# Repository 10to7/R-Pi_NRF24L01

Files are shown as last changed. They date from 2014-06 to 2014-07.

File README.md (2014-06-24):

Raspberry Pi NRF24L01
==================

A breakout board for one of the cheap NRF24L01 modules for Raspbery Pi.

##Module pin outs
Top view of the NRF24L01 modules pins are assumed to be:

8 Pin
```no-highlight
|GND  |3v3  |
|CE   |CSN  |
|SCK  |MOSI |
|MISO |IRQ (not connected)|
```

10 Pin
```no-highlight
|3v3  |3v3  |
|CE   |CSN  |
|SCK  |MOSI |
|MISO |IRQ (not connected)|
|GND  |GND  |
```

Please check that your modules match one of these pin layouts otherwise you risk damaging your raspberry pi or the NRF24L01 module.

| Top | Bottom |
|---|---|
|PCBfront|PCBback|

##Schematic
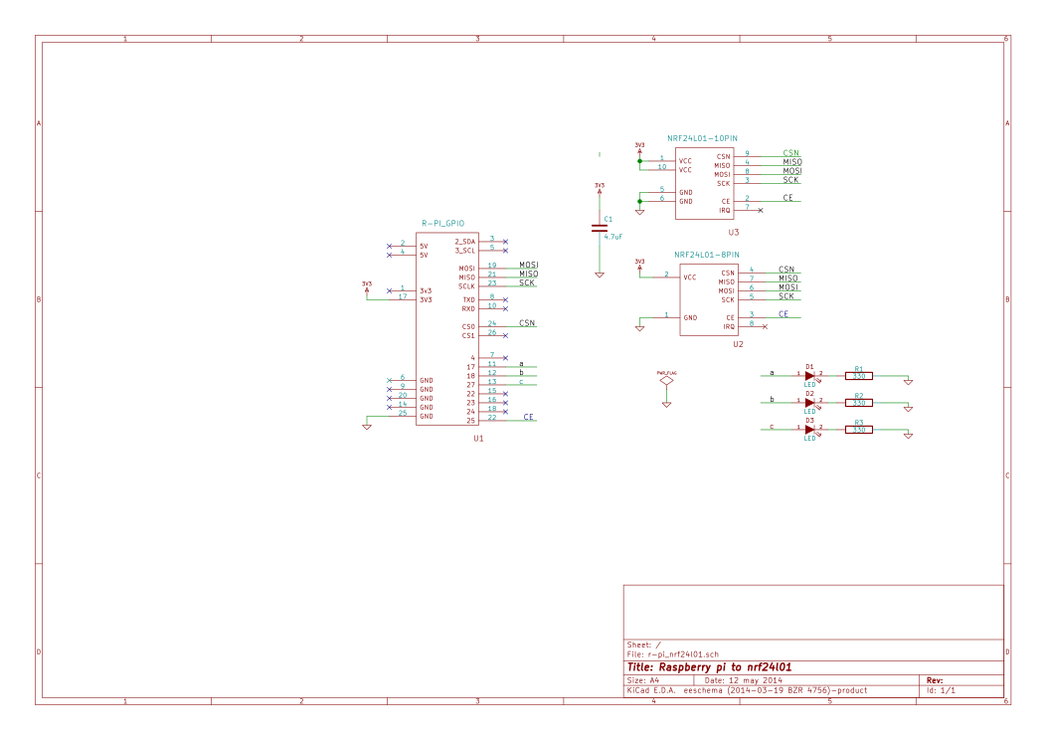
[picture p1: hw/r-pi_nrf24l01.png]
Schematic


[PCBfront]: front.png "PCB front"
[PCBback]: back.png "PCB Back"
[Schematic]: hw/r-pi_nrf24l01.png "Schematic"

Select the resistor values for the LED's. The raspberry pi can only source up to 16mA through the GPIO pins.
Suggested bill of matterials includes:

http://uk.farnell.com/ part numbers:

|Part | Description | Qty |Cost (GBP)|
|---|---|---|---|
|209-9221 | 0603 Red LED | 1 |0.054 |
|122-6372 | 0603 Green LED | 1 |0.052 |
|209-9222 | 0603 Orange LED | 1 | 0.056 |
|207-3958 | 0402 100 Ohm | 3 | 0.021 |
|175-9414 | 0805 4.7uF | 1 | 0.041 |

2.54mm female headers are also required for the board. A single 2x13 16 position header for the raspberry pi and a 2x4 8 position or 2x5 10 position female header for the NRF24L01 module.

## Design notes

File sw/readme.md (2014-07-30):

Example of running the NRF24L01 on the R-Pi
=====

Using Occidentals:
https://learn.adafruit.com/adafruit-raspberry-pi-educational-linux-distro/occidentalis-v0-dot-2

Ensure you enable SPI.

$ git clone https://github.com/10to7/RF24.git <br/>
$ cd RF24 <br />
$ cd librf24-rpi/librf24

Compile the library <br />
$ make                                
$ sudo make install              
$ sudo ldconfig -v | grep librf
     librf24.so.1 -> librf24.so.1.0

$ cd ../examples/ <br />
You should now be in RF24/librf24-rpi/librf24/examples

$ make

To run the programs, type 

$ sudo ./rpi-hub

To send data to the hub on a second raspberry pi run <br />
$ sudo ./sendto_hub

Alternatively use the nRF24_sendto_hub arduino script. You will need to add the nRF24 library to your arduino ide to get the NRF24.h

Wire up your module to the arduino as follows:

|NRF24L01 	| Arduino Nano	|
|---		|---		|
|CE		| D9		|
|SS		| D10		|
|MOSI		| D11		|
|MISO		| D12		|
|SCK		| D13		|
|3v3		| 3v3		|
|GND		| GND		|

Add an additional 100uF capacitor between 3v3 and GND. The arduino nano will be able to send to the R-Pi, but you may get a very high rate of faied messages on the arduino without the additional capacitor.

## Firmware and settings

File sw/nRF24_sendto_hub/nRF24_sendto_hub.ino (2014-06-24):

#include <SPI.h>
#include "nRF24L01.h"
#include "RF24.h"
#include "printf.h"

#define RF_SETUP 0x17
// Set up nRF24L01 radio on SPI pin for CE, CSN
RF24 radio(9,10);

// For best performance, use P1-P5 for writing and Pipe0 for reading as per the hub setting
// Below is the settings from the hub/receiver listening to P0 to P5
//const uint64_t pipes[6] = { 0x7365727631LL, 0xF0F0F0F0E1LL, 0xF0F0F0F0E2LL, 0xF0F0F0F0E3LL, 0xF0F0F0F0E4LL, 0xF0F0F0F0E5LL };
// Example below using pipe5 for writing
const uint64_t pipes[2] = { 0xF0F0F0F0E1LL, 0x7365727631LL };

// const uint64_t pipes[2] = { 0xF0F0F0F0E2LL, 0xF0F0F0F0E2LL };
// const uint64_t pipes[2] = { 0xF0F0F0F0E3LL, 0xF0F0F0F0E3LL };
// const uint64_t pipes[2] = { 0xF0F0F0F0E4LL, 0xF0F0F0F0E4LL };
// const uint64_t pipes[2] = { 0xF0F0F0F0E5LL, 0xF0F0F0F0E5LL };
// Pipe0 is F0F0F0F0D2 ( same as reading pipe )

char receivePayload[32];
uint8_t counter=0;

void setup(void)
{

  
  Serial.begin(57600);
  
  printf_begin();
  printf("Sending nodeID & 4 sensor data\n\r");

  radio.begin();

  // Enable this seems to work better
  radio.enableDynamicPayloads();

  radio.setDataRate(RF24_1MBPS);
  radio.setPALevel(RF24_PA_MAX);
  radio.setChannel(76);
  radio.setRetries(15,15);

  radio.openWritingPipe(pipes[0]); 
  radio.openReadingPipe(1,pipes[1]); 

      
  // Send only, ignore listening mode
  //radio.startListening();

  // Dump the configuration of the rf unit for debugging
  radio.printDetails(); 
  delay(1000); 
}

void loop(void)
{
  uint8_t Data1,Data2,Data3,Data4 = 0;
  char temp[5];
  bool timeout=0;

  // Get the last two Bytes as node-id
  uint16_t nodeID = pipes[0] & 0xff;

  // Use the last 2 pipes address as nodeID  
  // sprintf(nodeID,"%X",pipes[0]);
  
  char outBuffer[32]=""; // Clear the outBuffer before every loop
  unsigned long send_time, rtt = 0;
    
    // Get readings from sensors, change codes below to read sensors
    Data1 = counter++;
    Data2 = analogRead(0);
    Data3 = analogRead(1);
    Data4 = random(0,1000);
    
    if ( counter > 999 ) counter = 0;

    // Append the hex nodeID to the beginning of the payload    
    sprintf(outBuffer,"%2X",nodeID);
    
    strcat(outBuffer,",");
    
    // Convert int to strings and append with zeros if number smaller than 3 digits
    // 000 to 999
    
    sprintf(temp,"%03d",Data1);  
    strcat(outBuffer,temp);
    
    strcat(outBuffer,",");
    
    sprintf(temp,"%04d",Data2);
    strcat(outBuffer,temp);
    
    strcat(outBuffer,",");

    sprintf(temp,"%04d",Data3);
    strcat(outBuffer,temp);
   
    strcat(outBuffer,",");
   
    sprintf(temp,"%03d",Data4);
    strcat(outBuffer,temp); 
            
    printf("outBuffer: %s len: %d\n\r",outBuffer, strlen(outBuffer));

    send_time = millis();
    
    // Stop listening and write to radio 
    radio.stopListening();
    
    // Send to hub
    if ( radio.write( outBuffer, strlen(outBuffer)) ) {
       printf("Send successful\n\r"); 
    }
    else {
       printf("Send failed\n\r");
    }
  
    radio.startListening();
    delay(20);  

  while ( radio.available() && !timeout ) {

         uint8_t len = radio.getDynamicPayloadSize();
         radio.read( receivePayload, len); 
         
         receivePayload[len] = 0;
         printf("inBuffer:  %s\n\r",receivePayload);
        
         // Compare receive payload with outBuffer        
         if ( ! strcmp(outBuffer, receivePayload) ) {
             rtt = millis() - send_time;

             printf("inBuffer --> rtt: %i \n\r",rtt);            

             // Turn on buzzer to Pin 2
             digitalWrite(2,HIGH);

         }       
    
    // Check for timeout and exit the while loop
    if ( millis() - send_time > radio.getMaxTimeout() ) {
         Serial.println("Timeout!!!");
         timeout = 1;
     }          
      
     delay(10);
   } // End while  
     
    delay(250);
    digitalWrite(2,LOW); // Off the buzzer
    
  }

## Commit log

2014-05-18 Recreated and moved to new repository
    [r-pi_nrf24l01.brd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]
2014-06-03 incuded both a 10 pin and 8 pin header
    [r-pi_nrf24l01-B_Cu.gbl, r-pi_nrf24l01-B_Mask.gbs, r-pi_nrf24l01-B_SilkS.gbo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]
2014-06-22 Added board and schematic images to the project.
    [r-pi_nrf24l01.brd]
2014-06-22 removed the svg as it can't be displayed in a readme file die to cross site scripting vun. Created ong instead.
